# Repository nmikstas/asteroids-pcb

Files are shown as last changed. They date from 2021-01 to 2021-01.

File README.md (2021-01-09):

# asteroids-pcb
PCB source for the original Asteroids arcade game. This is a reproduction of a rev. 2 PCB. There are two sets of gerber files: the main Asteroids PCB and a small adapter board for IC 8C. 8C was a masked ROM that is no longer available. The adapter PCB will allow a 2716 EPROM to be used in it's place. A 28C16A-25 flash ROM will also work.

# NOTE
This project is part of my project portfolio: https://nmikstas.github.io/portfolio/

# Folder Structure
* Asteroids_PCB - The Kicad design files for the Asteroids PCB
* ROM_to_2716 - The Kicad source files for the ROM to EPROM adapter PCB
* Gerbers_Asteroids - The gerber files for the Asteroids PCB
* Gerbers_ROM_to_EPROM - The gerber files for the ROM to EPROM adapter PCB
* BOM - Bill of materials for the Asteroids PCB

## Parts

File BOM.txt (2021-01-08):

COMPONENT ID                              QUANTITY  PART NUMBER                   DESCRIPTION

A_6                                       1         Digikey 450-1650-ND           Push button switch (two pins cut off)
A_7, D_4, R_8                             3         Digikey 296-1668-5-ND         LS74 IC FF D-TYPE DUAL 1BIT 14DIP
A_8                                       1         Digikey 296-1634-5-ND         LS10 IC GATE NAND 3CH 3-INP 14DIP
A_9                                       1         Digikey 296-14711-5-ND        LS109 IC FF JK TYPE DUAL 1BIT 16DIP
A_10, BC_10, C_10, DE_10, E_10, FH_10,    11        Digikey 296-1645-5-ND         LS157 IC QUAD 2-1 DATA SEL/MUX 16-DIP 
F_3, H_3, J_3, K_3, F_6
A_12, C_12                                2         Digikey 296-1781-5-ND         TL082 J-FET Amplifier 2 Circuit 8-PDIP 
BC_12, E_12                               2         Digikey TL081IP-ND            TL081 J-FET Amplifier 1 Circuit 8-PDIP
B_2, C_2                                  2         Digikey 296-1653-5-ND         LS244 8 bits Bus Buffer 3 State out
B_4, D_5                                  2         Digikey 296-1665-5-ND         LS393 IC DUAL 4-BIT BINARY CNTR 14-DIP
B_5, H_10, L_5                            3         Digikey 296-1629-5-ND         LS04 IC INVERTER 6CH 6-INP 14DIP
B_6                                       1         Digikey 296-1643-5-ND         LS14 IC INVERTER SCHMITT 6CH 14DIP
B_7, C_5, C_7, D_7, P_8 C_4               6         Digikey 296-1646-5-ND         LS161 IC 4-BIT SYNC COUNTER 16-DIP
B_8, E_6, K_6, R_7                        4         Digikey 296-1633-5-ND         LS08 IC GATE AND 4CH 2-INP 14DIP
B_9, M_5, N_6                             3         Digikey 296-1658-5-ND         LS32 IC GATE OR 4CH 2-INP 14DIP 
B_10, D_10                                2         Digikey 296-1662-5-ND         LS374 IC FF D-TYPE SNGL 8BIT 20DIP 
B_11, D_11                                2         Found on Ebay or AliExpress   AD561J IC DAC 10BIT MONO VOLT IN 16DIP 
B_12, D_12, M_9, N_10, R_11               5         Digikey 296-9204-5-ND         4016B IC SWITCH QUAD 14DIP    
C_1, DE_1, F_1, NP_3 C_8                  5         Jameco 40002                  M2716 EPROM 2048 X 8 ****C_8 on adapter board****
C_3                                       1         Found on Ebay or AliExpress   R65C02 8-bit microprocessor
C_6, N_5                                  2         Digikey 296-1478-5-ND         LS00 IC GATE NAND 4CH 2-INP 14DIP 
K_5, C_9, D_9, E_9, F_9, H_9, J_9         7         Digikey 296-14886-5-ND        LS191 IC SYNC UP/DOWN COUNTER 16-DIP
D_2, E_2, M_4, N_4, P_4, R_4              6         Jameco 38957                  2114 RAM 1024 X 4 
D_6                                       1         Digikey 296-1627-5-ND         LS02 IC GATE NOR 4CH 2-INP 14DIP
D_8, F_10, N_7, N_11, P_7                 5         Digikey 296-3664-5-ND         LS174 IC FF D-TYPE SNGL 6BIT 16DIP
E_3, R_2                                  2         Digikey 296-1655-5-ND         LS245 Octal BUS Transceivers, 3 State out  
E_4, L_3                                  2         Digikey 296-1640-5-ND         LS139 IC DUAL 2-4 LINE DECODER 16-DIP 
E_5                                       1         Digikey 296-3670-5-ND         LS20 IC GATE NAND 2CH 4-INP 14DIP 
E_7, E_8, L_6                             3         Digikey 296-27985-5-ND        LS42 IC 4-LINE BCD/DEC DECOD 16-DIP
F_4, H_4, J_4                             3         Digikey 296-34025-5-ND        LS670 IC 4X4 REG FILE TRI-ST 16-DIP
F_5, H_5, J_5                             3         Digikey 296-1649-5-ND         LS193 IC 4-BIT UP/DOWN COUNTER 16-DIP
F_7, H_7, J_7, K_7                        4         Digikey 296-1657-5-ND         LS273 IC FF D-TYPE SNGL 8BIT 20DIP
F_8, H_8, J_8, K_8                        4         Jameco 50796                  SN7497 Rate Multiplier
H_6, J_6                                  2         Digikey 296-3701-5-ND         LS367 IC BUF NON-INVERT 5.25V 16DIP
J_10, L_10                                2         Digikey 296-14888-5-ND        LS251 IC 8-IN DATASELCT/MUX 3ST 16DIP 
K_9, P_9, R_9                             3         Digikey 296-1647-5-ND         LS164 IC 8-BIT SHIFT REGISTER 14-DIP
L_8, P_11                                 2         Digikey 296-9542-5-ND         LM324 IC OPAMP GP 1.2MHZ 14DIP 
L_9, M_8, N_8, R_10                       4         Digikey 296-1411-5-ND         555 IC OSC SINGLE TIMER 100KHZ 8-DIP
M_6                                       1         Digikey 296-31579-1-ND        HC283 ****IC 4BIT BINARY FULL ADDER 16SOIC on adapter board****
M_7                                       1         Digikey 296-1648-5-ND         LS175 IC FF D-TYPE SNGL 4BIT 16DIP
M_10                                      1         Digikey 296-14889-5-ND        LS259 IC 8-BIT ADDRESSBLE LATCH 16-DIP
M_12                                      1         Digikey 450-1404-ND           SWITCH ROCKER DIP SPST 60MA 5V  
N_9                                       1         Digikey 296-15069-5-ND        LS06 IC INVERTER OPEN COL 6CH 14DIP
P_5                                       1         Digikey 296-1669-5-ND         LS86 IC GATE XOR 4CH 2-INP 14DIP  
P_6                                       1         Digikey 296-33981-5-ND        LS253 IC 4-1 DATA SELECT/MUX 16-DIP
P_10                                      1         Found on Ebay or AliExpress   NE566 VCO ****WARNING**** There are many Chinese knockoffs floating around that do not work! Avoid LM566!
R_6                                       1         Digikey 450-1417-ND           SWITCH ROCKER DIP SPST 60MA 5V  
U7805                                     1         Digikey 497-1443-5-ND         IC REG LINEAR 5V 1.5A TO220AB 
U7812                                     1         Digikey LM340T-12/NOPB-ND     IC REG LINEAR 12V 1A TO220-3 
U7815                                     1         Digikey 497-8352-5-ND         IC REG LINEAR 15V 1.5A TO220AB 
U7915                                     1         Digikey LM7915CT/NOPB-ND      IC REG LINEAR -15V 1.5A TO220-3 
Y1                                        1         Digikey X429-ND               CRYSTAL 12.0960MHZ SERIES T/H
C1, C2, C3, C4, C5, C6, C7, C8, C9, C10,  78        Digikey 399-4491-1-ND         CAP CER 0.1UF 50V X7R AXIAL  
C11, C12, C13, C14, C15, C16, C17, C18, 
C20, C21, C22, C23, C26, C28, C29, C30, 
C31, C34, C41, C42, C43, C44, C49, C52, 
C53, C57, C60, C61, C65, C66, C71, C72, 
C73, C74, C75, C76, C77, C78, C79, C80, 
C81, C82, C83, C84, C85, C91, C94, C111, 
C112, C37, C51, C54, C63, C95, C96, C99, 
C100, C103, C104, C107, C108, C114, C115, 
C116, C120, C121, C122, C123
C19                                       1         Digikey 1572-1048-ND          100µF 25V Aluminum Electrolytic Capacitors Axial
C24, C35, C47, C50, C62, C113             6         Digikey 399-13735-1-ND        1uf CAP CER 1UF 50V X7R AXIAL
C25, C70, C90, C92, C93                   5         Digikey 1572-1279-ND          CAP ALUM 1UF 20% 50V AXIAL
C27, C32, C36, C40, C55, C58              6         Digikey 399-4453-1-ND         10000pF Unpolarized capacitor
C33                                       1         Digikey 399-14070-1-ND        .22uF Unpolarized capacitor  
C38, C39, C45, C48                        4         Digikey 399-13620-ND          CAP TANT 10UF 20% 20V AXIAL 
C46                                       1         Digikey 399-4512-1-ND         .047uf Unpolarized capacitor  
C56                                       1         Digikey 399-4450-1-ND         1000pf Unpolarized capacitor  
C59                                       1         Digikey 445-173538-1-ND       270pf Unpolarized capacitor  
C64, C67, C68, C69                        4         Digikey 478-3154-1-ND         CAP CER 0.1UF 100V Z5U AXIAL 
C86, C87                                  2         Digikey 1572-1496-ND          CAP ALUM 470UF 20% 35V AXIAL
C88                                       1         Digikey 445-173545-1-ND       390pf Unpolarized capacitor  
C89                                       1         Digikey 399-4447-1-ND         100pf Unpolarized capacitor  
C97, C105                                 2         Digikey CF14JT6K80CT-ND       *****6.8k Resistor***** 
C98, C106, C118, C119                     4         Digikey C410C221J1G5TA7200    220pf Unpolarized capacitor  
C102, C110                                2         Digikey 399-9746-ND           68pf Unpolarized capacitor   
C117                                      1         Digikey 1572-1393-ND          CAP ALUM 22UF 20% 35V AXIAL
CR1, CR2, CR3, CR4, CR6, CR7, CR8, CR15   8         Digikey 1N914FS-ND            1N914 Diode
CR5                                       1         Digikey 732-5015-ND           LED Blue
CR9, CR10, CR11, CR12                     4         Digikey 641-1310-1-ND         1N4001 Diode
CR13, CR14                                2         Digikey 1N756ACSCT-ND         DIODE ZENER 8.2V 500MW DO35
L2, L3, L4, L5, L6, L7, L8, L12           8         Digikey 77F101J-TR-RCCT-ND    FIXED IND 100UH 275MA 2.5 OHM TH
Plastic tabs                              7         Digikey RPC1553-ND            MOUNTING BUTTON 0.330" NYLN NRTL
Q1, Q2, Q3, Q4, Q5, Q7, Q10, Q16, Q17     9         Digikey 2N3906-APCT-ND        Transistor PNP (general) 
Q6, Q8, Q9, Q14, Q15                      5         Digikey 2N3904-APCT-ND        Transistor NPN (general)  
Q11, Q12, Q13                             3         Digikey TIP122GOS-ND          Darlington Transistor NPN (general)
R120, R126                                2         Digikey 3352H-103LF-ND        10k Potentiometer 
R116, R122                                2         Digikey CF14JT3K30CT-ND       3.3k Resistor  
R1, R2, R3, R4, R5, R6, R7, R8, R34,      12        Digikey CF14JT22K0CT-ND       22K Resistor  
R41, R45, R50
R9, R10, R11, R12, R13, R14, R15, R16,    31        Digikey CF14JT10K0CT-ND       10K Resistor
R17, R18, R28, R33, R69, R110, R111,
R130, R131, R38, R54, R58, R59, R60,
R63, R70, R79, R80, R103, R135, R136, 
R138, R139
R19, R20, R21, R22, R23, R24, R25, R26,   22        Digikey CF14JT470RCT-ND       470 Resistor
R32, R87, R88, R89, R90, R91, R92, R93,
R94, R95, R96, R97, R98, R99
R27, R29, R86, R53, R73, R85, R132, R134  8         Digikey CF14JT1K00CT-ND       1K Resistor 
R30, R31                                  2         Digikey CF14JT330RCT-ND       330 Resistor 
R115                                      1         Digikey CF14JT220RCT-ND       220 Resistor
R35, R100                                 2         Digikey CF14JT1K20CT-ND       1.2k Resistor  
R36, R55, R75, R117, R123, R133, R141     7         Digikey CF14JT2K20CT-ND       2.2k Resistor
R37, R137, R140, R144 R82, R102           6         Digikey CF14JT4K70CT-ND       4.7k Resistor 
R39, R64, R106, R107, R108                5         Digikey CF14JT3K90CT-ND       3.9k Resistor
R40, R62, R67                             3         Digikey PPC5.6KW-1CT-ND       5.6k Resistor  
R42, R76, R114, R44, R48, R78, R83        7         Digikey CF14JT47K0CT-ND       47k Resistor
R43                                       1         Digikey CF14JT12K0CT-ND       12k Resistor  
R46, R81, R84, R143                       4         Digikey CF14JT100KCT-ND       100K Resistor  
R47                                       1         Digikey CF14JT220KCT-ND       220K Resistor  
R49 R104, R128, R129                      4         Digikey CF14JT6K80CT-ND       6.8K Resistor
R51, R146                                 2         Digikey CF14JT18K0CT-ND       18K Resistor  
R52                                       1         Digikey CF14JT33K0CT-ND       33k Resistor   
R56, R65, R74, R142                       4         Digikey CF14JT3K30CT-ND       3.3k Resistor
R57, R61                                  2         Digikey CF14JT680RCT-ND       680  Resistor  
R66                                       1         Digikey CF14JT2K70CT-ND       2.7k Resistor  
R68                                       1         Digikey CF14JT15K0CT-ND       15k Resistor  
R71                                       1         Digikey CF14JT68R0CT-ND       68 Resistor  
R72                                       1         Digikey CF14JT68R0CT-ND       27 Resistor    
R77                                       1         Digikey CF14JT39K0CT-ND       39K Resistor  
R101                                      1         Digikey CF14JT270KCT-ND       270k Resistor  
R105, R109                                2         Digikey CF14JT120RCT-ND       120 Resistor  
R112, R113                                2         Digikey CF14JT270RCT-ND       270 Resistor   
R145                                      1         Digikey CF14JT56K0CT-ND       56K Resistor
T1, T2, T3, T4, T5, T6, T7, T8, T9, T10,  17        NONE                          Test point
T11, T12, T13, T14, T15, T16, T17  

****Sockets****
8-pin:                                    9         Jameco 112206                 8-Pin IC Socket Dual Wipe Low Profile 0.30 Inch Wide
14-pin:                                   33        Jameco 112214                 Socket IC 14-Pin Dual Wipe Low Profile 0.3 Inch Wide
16-pin:                                   55        Jameco 112222                 IC Socket 16-Pin Dual Wipe Low Profile 0.3 Inch Wide
18-pin:                                   6         Jameco 112231                 18-Pin 0.3 Inch Wide Low Profile Dual Wipe IC Socket
20-pin:                                   10        Jameco 112248                 20-Pin 0.3 Inch Wide Low Profile Dual Wipe IC Socket
24-pin:                                   4         Jameco 112264                 24-Pin Dual Wipe Low Profile IC Socket 0.6 Inch Wide
40-pin:                                   1         Jameco 112311                 40-Pin Dual Wipe Low Profile IC Socket 0.60 Inch Wide

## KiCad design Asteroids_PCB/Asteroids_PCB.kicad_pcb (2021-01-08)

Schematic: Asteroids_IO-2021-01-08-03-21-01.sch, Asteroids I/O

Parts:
A_12: 082; DIP8
BC_12: 081; DIP8
B_11: AD561J; DIP16
B_11A1: ALT_DAC
B_12: 4016B; DIP14
C24, C35, C47, C50, C62: 1uf; TantC
C27, C32: .01uF; DiskC
C33: .22uF; Mylar_C
C34, C65, C71, C72, C73, C74, C75, C76, C77, C78, C79, C80, C81, C82, C83: .1uF; GenericC
C36, C40, C55, C58: .01uf; DiskC
C37, C51, C54, C63, C95, C96, C99, C100, C103, C104, C107, C108, C114, C115, C116, C120, C121, C122, C123: .1uf; GenericC
C38, C39, C45, C48: 10uf; TantC2
C46: .047uf; Mylar_C
C56: .001uf; DiskC
C59: 270pf; Mylar_C
C64: .1uF; Mylar_C
C67, C68, C69: .1uf; Mylar_C
C88: 390pf; SmallC
C89: 100pf; SmallC
C97, C105: 10pf; SmallC
C98, C106, C118, C119: 220pf; SmallC
C102, C110: 68pf; SmallC
C113: 1uF; TantC
CR2, CR3, CR4, CR6, CR7, CR8: 1N914; Diode1
CR15: 1N914; GenericR
C_6: LS00; DIP14
C_12: 082; DIP8
D_6: LS02; DIP14
D_11: AD561J; DIP16
D_11A1: ALT_DAC
D_12: 4016B; DIP14
E_12: 081; DIP8
H_10: LS04; DIP14
J20: J20
J21: J21
J_10: LS251; DIP16
K_9: LS164; DIP14
L2, L3, L4, L5, L6, L7, L8, L12: 100uH; GenericL
L_5: LS04; DIP14
L_8: 324; DIP14
L_9: 555; DIP8
L_10: LS251; DIP16
M_8: 555; DIP8
M_9: 4016B; DIP14
M_10: LS259; DIP16
M_12: SW_DIP_x04; DIP8
N_5: LS00; DIP14
N_6: LS32; DIP14
N_7, N_11: LS174_; DIP16
N_8: 555; DIP8
N_9: LS06; DIP14
N_10: 4016B; DIP14
P_2: DIP20_DUMMY; DIP20
P_5: LS86; DIP14
P_6: LS253; DIP16
P_7: LS174_; DIP16
P_8: LS161; DIP16
P_9: LS164; DIP14
P_10: 566; DIP8
P_11: 324; DIP14
Q1, Q2, Q3, Q4, Q5, Q7, Q10, Q16, Q17: 2N3906; GenericQ
Q6: 2N3643; GenericQ
Q8, Q9: 2N3904; GenericQ
Q11, Q12, Q13: 2N6044
Q14, Q15: MPSA06S; GenericQ
R19, R20, R21, R22, R23, R24, R25, R26, R87, R88, R89, R90, R91, R92, R93, R94, R95, R96, R97, R98, R99: 470; GenericR
R34, R41: 22k; GenericR
R35, R100: 1.2k; GenericR
R36, R75, R117, R123, R133: 2.2k; GenericR
R37, R137, R140, R144: 4.7k; GenericR
R38, R54, R58, R59, R60, R63, R70, R79, R80, R103, R116, R122, R135, R136, R138, R139: 10k; GenericR
R39, R64, R106, R107, R108: 3.9k; GenericR
R40, R62, R67: 5.6k; GenericR
R42, R76, R114: 47k; GenericR
R43: 12k; GenericR
R44, R48, R78, R83: 47K; GenericR
R45, R50: 22K; GenericR
R46, R81, R84, R143: 100K; GenericR
R47: 220K; GenericR
R49: 6.8K; GenericR
R51, R146: 18K; GenericR
R52: 33k; GenericR
R53, R73, R85, R132, R134: 1k; GenericR
R56, R65: 3.3k; GenericR
R57, R61: 680; GenericR
R66: 2.7k; GenericC
R68: 15k; GenericR
R69, R110, R111: 10K; GenericR
R71: 68; GenericR
R72: 27; GenericR
R74, R142: 3.3K; GenericR
R77: 39K; GenericR
R82, R102: 4.7K; GenericR
R86: 1K; GenericR
R101: 270k; GenericR
R104, R128, R129: 6.8k; GenericR
R105, R109: 120; GenericR
R115: 330; GenericR
R120, R126: 10k; Pot
R141: 2.2K; GenericR
R145: 56K; GenericR
R_3: 8316E; DDIP24
R_6: SW_x08; DIP16
R_7: LS08; DIP14
R_8: LS74; DIP14
R_9: LS164; DIP14
R_10: 555; DIP8
R_11: 4016B; DIP14
T1: TPAD1; TPAD
T2: TPAD2; TPAD
T3: TPAD3; TPAD
T4: TPAD4; TPAD
T5: TPAD5; TPAD
T6: TPAD6; TPAD
T7: TPAD7; TPAD
T10, T11, T12, T13, T14, T15, T16, T17: TPAD
TP10: START 2; TEST_POINT
TP11: START 1; TEST_POINT
TP12: COIN R; TEST_POINT
TP13: COIN C; TEST_POINT
TP14: COIN L; TEST_POINT
TP20: AUD 1; TEST_POINT
TP50: X_OUT; TEST_POINT
TP60: Y_OUT; TEST_POINT
TP70: Z_OUT; TEST_POINT

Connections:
3KHz: L_10.3, R_11.11; also elsewhere on the board
3MHz: C_6.2, C_6.13, K_9.8; also elsewhere on the board
12KHz: D_6.2, P_8.2, P_9.8, R_9.8; also elsewhere on the board
22V0: C37.1, C65.2, L_8.4, P_11.4; also elsewhere on the board
36VAC1_: J20.X; also elsewhere on the board
36_VAC2_: J20.20; also elsewhere on the board
+5DAC: B_11.14, B_11A1.20, C96.2, C104.2, D_11.14, D_11A1.20; also elsewhere on the board
+5V: C34.1, C51.1, C54.1, C62.1, C63.2, C_6.14, D_6.14, H_10.14, J20.2, J20.21, J20.B, J20.Y, J21.45, J21.46, J21.47, J21.48, J21.49, J21.50, J_10.16, K_9.14, L_5.14, L_9.8, L_10.16, M_8.8, M_9.1, M_9.3, M_9.9, M_9.10, M_10.16, N_5.14, N_6.14, N_7.16, N_8.8, N_9.14, N_11.16, P_2.20, P_5.14, P_6.16, P_7.16, P_8.16, P_9.14, P_11.3, P_11.5, P_11.10, P_11.12, Q9.3, R19.1, R20.1, R21.1, R22.1, R23.1, R24.1, R25.1, R26.1, R39.1, R49.1, R50.1, R67.1, R71.1, R79.1, R80.1, R87.2, R88.2, R89.2, R90.2, R91.2, R92.2, R93.2, R94.2, R95.2, R96.2, R97.2, R98.2, R99.2, R100.1, R132.2, R134.1, R_3.21, R_3.24, R_7.14, R_8.14, R_9.14, R_10.4, R_10.8, R_11.14; also elsewhere on the board
+8.2V: B_12.14, CR15.1, D_12.14, Q10.1, Q16.1, Q17.1, R141.1, R144.1; also elsewhere on the board
+12V: CR3.2, M_9.14, N_10.14, P_10.8, R52.1, R54.1, R56.1, R59.1, R60.1, R62.1, R63.1, R65.1, R70.1, R85.1; also elsewhere on the board
+15V: A_12.8, BC_12.7, C100.2, C108.2, C121.2, C123.2, C_12.8, E_12.7; also elsewhere on the board
-8.2V: B_12.7, D_12.7, R115.2, R142.2, R145.2; also elsewhere on the board
-15V: A_12.4, BC_12.4, B_11.3, B_11A1.17, C95.1, C99.2, C103.1, C107.2, C120.2, C122.2, C_12.4, D_11.3, D_11A1.17, E_12.4; also elsewhere on the board
A0: J21.17; also elsewhere on the board
A1: J21.18; also elsewhere on the board
A2: J21.15; also elsewhere on the board
A3: J21.16; also elsewhere on the board
A4: J21.13; also elsewhere on the board
A5: J21.14; also elsewhere on the board
A6: J21.11; also elsewhere on the board
A7: J21.12; also elsewhere on the board
A8: J21.9; also elsewhere on the board
A9: J21.10; also elsewhere on the board
A10: J21.7; also elsewhere on the board
A11: J21.8; also elsewhere on the board
A12: J21.21; also elsewhere on the board
A13: J21.22; also elsewhere on the board
A14: J21.19; also elsewhere on the board
A15: J21.20; also elsewhere on the board
AB0: J_10.11, L_10.11, M_10.1, P_6.14; also elsewhere on the board
AB1: J_10.10, L_10.10, M_10.2, P_6.2; also elsewhere on the board
AB2: J_10.9, L_10.9, M_10.3; also elsewhere on the board
AB8: P_5.4; also elsewhere on the board
AB9: N_5.5; also elsewhere on the board
AB10: L_5.5; also elsewhere on the board
AB12: D_6.8; also elsewhere on the board
AM0: R_3.8; also elsewhere on the board
AM1: R_3.7; also elsewhere on the board
AM2: R_3.6; also elsewhere on the board
AM3: R_3.5; also elsewhere on the board
AM4: R_3.4; also elsewhere on the board
AM5: R_3.3; also elsewhere on the board
AM6: R_3.2; also elsewhere on the board
AM7: R_3.1; also elsewhere on the board
AM8: R_3.23; also elsewhere on the board
AM9: R_3.22; also elsewhere on the board
AM10: L_5.3, R_3.19; also elsewhere on the board
AUDIO_1_: C113.2, J20.5, P_11.8, R86.1, TP20.1, TP20.2
AUDIO_2_: J20.E, P_11.14, R110.1
BVLD: K_9.2; also elsewhere on the board
C1: C115.1, J20.4, M_12.7, M_12.8, Q11.2
C_CN_SW_: C81.2, J20.12, L7.1
D0: J21.29; also elsewhere on the board
D1: J21.30; also elsewhere on the board
D2: J21.27; also elsewhere on the board
D3: J21.28; also elsewhere on the board
D4: J21.25; also elsewhere on the board
D5: J21.26; also elsewhere on the board
D6: J21.23; also elsewhere on the board
D7: J21.24; also elsewhere on the board
DACX1*: D_11.4, D_11A1.12; also elsewhere on the board
DACX2*: D_11.5, D_11A1.11; also elsewhere on the board
DACX3*: D_11.6, D_11A1.10; also elsewhere on the board
DACX4*: D_11.7, D_11A1.9; also elsewhere on the board
DACX5*: D_11.8, D_11A1.8; also elsewhere on the board
DACX6*: D_11.9, D_11A1.7; also elsewhere on the board
DACX7*: D_11.10, D_11A1.6; also elsewhere on the board
DACX8*: D_11.11, D_11A1.5; also elsewhere on the board
DACX9*: D_11.12, D_11A1.4; also elsewhere on the board
DACX10*: D_11.13, D_11A1.3; also elsewhere on the board
DACY1*: B_11.4, B_11A1.12; also elsewhere on the board
DACY2*: B_11.5, B_11A1.11; also elsewhere on the board
DACY3*: B_11.6, B_11A1.10; also elsewhere on the board
DACY4*: B_11.7, B_11A1.9; also elsewhere on the board
DACY5*: B_11.8, B_11A1.8; also elsewhere on the board
DACY6*: B_11.9, B_11A1.7; also elsewhere on the board
DACY7*: B_11.10, B_11A1.6; also elsewhere on the board
DACY8*: B_11.11, B_11A1.5; also elsewhere on the board
DACY9*: B_11.12, B_11A1.4; also elsewhere on the board
DACY10*: B_11.13, B_11A1.3; also elsewhere on the board
DB0: N_7.6, N_11.14, P_2.17, P_6.7; also elsewhere on the board
DB1: N_7.11, N_11.3, P_2.18, P_6.9; also elsewhere on the board
DB2: N_7.4, N_11.13, P_2.19, P_7.6; also elsewhere on the board
DB3: N_7.13, N_11.4, P_2.16, P_7.11; also elsewhere on the board
DB4: N_7.3, N_11.11, P_2.15, P_7.4; also elsewhere on the board
DB5: N_11.6, P_2.14, P_7.13; also elsewhere on the board
DB6: P_2.13, P_7.3; also elsewhere on the board
DB7: J_10.6, L_10.6, M_10.13, P_2.12, P_7.14; also elsewhere on the board
DDMA0: P_2.3, R_3.9; also elsewhere on the board
DDMA1: P_2.2, R_3.10; also elsewhere on the board
DDMA2: P_2.1, R_3.11; also elsewhere on the board
DDMA3: P_2.4, R_3.13; also elsewhere on the board
DDMA4: P_2.5, R_3.14; also elsewhere on the board
DDMA5: P_2.6, R_3.15; also elsewhere on the board
DDMA6: P_2.7, R_3.16; also elsewhere on the board
DDMA7: P_2.8, R_3.17; also elsewhere on the board
DIAG_STEP_: C71.2, J20.K, L4.1
EXPAUD0: P_7.12, R_7.1
EXPAUD1: P_7.5, R_7.12
EXPAUD2: P_7.10, R_7.4
EXPAUD3: P_7.7, R_7.9
EXPITCH0: L_5.11, N_6.12, P_7.2, P_8.4
EXPITCH1: N_6.13, P_7.15, P_8.3
EXPLOSND: C24.2, R40.1, R41.1, R42.1, R43.1, R82.2
FIRE_: C72.2, J20.T, L_10.15, R89.1
GND: B_11.1, B_11A1.1, B_11A1.2, B_11A1.13, B_11A1.19, C24.1, C27.2, C32.2, C33.2, C34.2, C35.2, C36.2, C37.2, C38.2, C39.1, C40.2, C45.2, C46.2, C47.2, C48.1, C50.2, C51.2, C54.2, C55.2, C58.2, C63.1, C64.2, C65.1, C71.1, C72.1, C73.1, C74.1, C75.1, C76.1, C77.1, C78.1, C79.1, C80.1, C81.1, C82.1, C83.1, C95.2, C96.1, C98.2, C99.1, C100.1, C103.2, C104.1, C106.2, C107.1, C108.1, C114.2, C115.2, C116.2, C118.2, C119.2, C120.1, C121.1, C122.1, C123.1, CR7.1, C_6.7, D_6.7, D_11.1, D_11A1.1, D_11A1.2, D_11A1.13, D_11A1.19, H_10.7, J20.1, J20.11, J20.22, J20.A, J20.U, J20.V, J20.Z, J21.1, J21.2, J21.3, J21.4, J21.5, J21.6, J_10.8, K_9.7, L_5.7, L_8.5, L_8.10, L_8.11, L_9.1, L_10.8, M_8.1, M_9.7, M_10.8, N_5.7, N_6.7, N_7.8, N_8.1, N_9.7, N_10.1, N_10.3, N_10.7, N_11.8, P_2.10, P_5.7, P_6.8, P_7.8, P_8.8, P_9.7, P_10.1, P_11.11, Q7.3, Q8.1, Q11.3, Q12.3, Q13.3, Q14.1, Q15.1, R34.2, R44.2, R53.2, R72.2, R116.2, R122.2, R128.2, R129.2, R137.2, R140.2, R_3.12, R_3.18, R_6.1, R_6.2, R_6.3, R_6.4, R_6.5, R_6.6, R_6.7, R_6.8, R_7.7, R_8.7, R_9.7, R_10.1, R_11.7; also elsewhere on the board
GO: H_10.1; also elsewhere on the board
GW: C_6.3; also elsewhere on the board
HALT: L_10.2; also elsewhere on the board
HYPRSPC_: C73.2, J20.10, L_10.1, R88.1
INV: B_12.13, D_12.13, Q16.3, R142.1, R143.2
L1: C114.1, J20.D, M_12.1, Q12.2
LIFEEN: M_10.10, R79.2, R_11.12
LIFESND: R78.2, R_11.10
L_CN_SW_: C82.2, J20.13, L5.1
NINV: B_12.12, D_12.12, Q17.3, R145.1
NOISE: N_5.3, R_8.12, R_9.1, R_9.2, R_11.9
NO_CON: J20.19, R146.2
unnamed 204: D_6.12; also elsewhere on the board
unnamed 206: L_5.12; also elsewhere on the board
unnamed: A_12.2, C110.1, R122.1, R126.3
unnamed: A_12.3, B_12.2, B_12.10
unnamed: A_12.5, R129.1
unnamed: A_12.7, B_12.8, C105.1, R123.1, R135.2
unnamed: BC_12.2, R135.1, R136.2
unnamed: BC_12.3, R137.1
unnamed: BC_12.6, B_12.4, R136.1
unnamed 223: C_6.1; also elsewhere on the board
unnamed 232: C_6.5; also elsewhere on the board
unnamed: B_11.16, R123.2
unnamed: B_11A1.14, T7.1
unnamed: B_11A1.15, T6.1
unnamed: B_11A1.16, T5.1
unnamed: B_12.1, B_12.3, C118.1
unnamed: B_12.9, B_12.11, C106.1
unnamed: C27.1, CR2.1, Q2.2, R44.1, R45.1, R46.1, R47.1, R48.1
unnamed: C32.1, N_8.5
unnamed: C33.1, N_8.2, N_8.6, Q2.3, R51.2
unnamed: C35.1, M_8.2, M_8.6, R57.2
unnamed: C36.1, M_8.5
unnamed: C38.1, L_8.3, M_9.4, Q3.3
unnamed: C39.2, M_9.8, R58.1
unnamed: C40.1, L_9.5
unnamed: C45.1, N_10.2, N_10.9, Q6.2, R69.2, R_10.2, R_10.6
unnamed: C46.1, P_10.7
unnamed: C47.1, L_8.12, M_9.11, Q1.3
unnamed: C48.2, M_9.2, R66.1
unnamed: C50.1, L_9.2, L_9.6, R61.2
unnamed: C55.1, R_10.5
unnamed: C56.1, P_10.6, R70.2
unnamed: C56.2, P_10.5, Q6.3, R62.2
unnamed: C58.1, Q7.1, Q8.3, Q9.2, R71.2
unnamed: C59.1, Q8.2, R73.1
unnamed: C59.2, H_10.4, R73.2
unnamed: C62.2, R75.1, R76.2
unnamed: C64.1, N_8.3, R74.1
unnamed: C67.1, P_11.7, R101.1, R104.2
unnamed: C67.2, C68.1, R76.1, R100.2
unnamed: C68.2, P_11.6, R101.2
unnamed: C69.2, P_11.2, R103.2, R104.1
unnamed: C88.1, C89.1, CR15.2, Q10.2, R114.1
unnamed: C88.2, C_6.11, R114.2
unnamed: C97.1, C_12.7, D_12.8, R117.1, R138.2
unnamed: C97.2, C_12.6, D_11.2, D_11.15
unnamed: C98.1, D_12.9, D_12.11
unnamed: C102.1, C_12.2, R116.1, R120.3
unnamed: C113.1, R111.2
unnamed: C119.1, D_12.1, D_12.3
unnamed: CR2.2, R49.2
unnamed: CR3.1, CR4.2
unnamed: CR4.1, Q1.2, Q3.2, R53.1
unnamed: CR6.1, M_8.3
unnamed: CR7.2, N_10.4, R64.1
unnamed: CR8.1, L_9.3
unnamed 305: C_6.6; also elsewhere on the board
unnamed 306: C_6.8; also elsewhere on the board
unnamed: C_6.10, D_6.10
unnamed 321: L_5.13; also elsewhere on the board
unnamed 327: H_10.13; also elsewhere on the board
unnamed 330: H_10.6; also elsewhere on the board
unnamed: C_12.3, D_12.2, D_12.10
unnamed: C_12.5, R128.1
unnamed 334: P_5.6; also elsewhere on the board
unnamed: D_6.1, R_8.11
unnamed: D_6.3, L_5.2, P_8.9
unnamed 348: D_6.4; also elsewhere on the board
unnamed 349: D_6.5, D_6.9; also elsewhere on the board
unnamed 350: D_6.11; also elsewhere on the board
unnamed: D_11.16, R117.2
unnamed: D_11A1.14, T4.1
unnamed: D_11A1.15, T3.1
unnamed: D_11A1.16, T2.1
unnamed: D_11A1.18, T1.1
unnamed: D_12.4, E_12.6, R139.1
unnamed: E_12.2, R138.1, R139.2
unnamed: E_12.3, R140.1
unnamed 397: H_10.11; also elsewhere on the board
unnamed 400: H_10.8; also elsewhere on the board
unnamed: H_10.3, K_9.3
unnamed 409: H_10.5; also elsewhere on the board
unnamed 410: H_10.9; also elsewhere on the board
unnamed: J_10.1, L8.2, R93.1, TP11.1, TP11.2
unnamed: J_10.2, L12.2, R98.1, TP12.1, TP12.2
unnamed: J_10.3, L7.2, R97.1, TP13.1, TP13.2
unnamed: J_10.4, L5.2, R96.1, TP14.1, TP14.2
unnamed: J_10.15, L6.2, R95.1, TP10.1, TP10.2
unnamed: L3.2, L_10.13, R91.1
unnamed: L4.2, L_10.14, R90.1
unnamed 460: L_5.6; also elsewhere on the board
unnamed: L_5.1, P_8.15
unnamed 464: L_5.4; also elsewhere on the board
unnamed: L_5.10, P_8.5
unnamed: L_8.1, Q4.2
unnamed: L_8.2, Q4.1, R56.2
unnamed: L_8.6, L_8.7
unnamed: L_8.8, L_8.9
unnamed: L_8.13, Q5.1, R65.2
unnamed: L_8.14, Q5.2
unnamed: L_9.7, Q5.3, R61.1
unnamed 486: N_6.8; also elsewhere on the board
unnamed: M_8.7, Q4.3, R57.1
unnamed: M_9.5, M_9.6, N_9.10, R60.2
unnamed: M_9.12, M_9.13, N_9.4, R59.2
unnamed: M_10.6, N_9.1
unnamed: N_5.1, N_5.2, P_5.3
unnamed: N_5.6, P_5.5
unnamed: N_5.8, N_6.9
unnamed: N_6.11, P_8.6
unnamed: N_7.2, N_8.4
unnamed: N_7.5, R48.2
unnamed: N_7.7, R47.2
unnamed: N_7.10, R46.2
unnamed: N_7.12, R45.2
unnamed: N_7.14, N_7.15
unnamed: N_8.7, R51.1
unnamed: N_9.6, N_9.9, R132.1, R133.2
unnamed: N_9.8, Q15.2, R134.2
unnamed: N_10.8, R68.2
unnamed: N_9.12, N_10.13, R85.2
unnamed: N_11.2, R105.1
unnamed: N_11.5, R106.2
unnamed: N_11.7, R107.2
unnamed: N_11.10, R108.2
unnamed: N_11.15, R109.1
unnamed: P_5.1, P_9.12
unnamed: P_5.2, R_9.12
unnamed: P_6.3, R19.2, R_6.16
unnamed: P_6.4, R21.2, R_6.14
unnamed: P_6.5, R23.2, R_6.12
unnamed: P_6.6, R26.2, R_6.10
unnamed: P_6.10, R25.2, R_6.9
unnamed: P_6.11, R24.2, R_6.11
unnamed: P_6.12, R22.2, R_6.13
unnamed: P_6.13, R20.2, R_6.15
unnamed: P_9.1, P_9.2, R_9.13
unnamed: P_11.9, R77.1, R78.1, R81.1, R82.1, R83.1, R84.1, R86.2, R102.1
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

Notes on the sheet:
PLAYER INPUT CIRCUITRY
OPTIONS INPUT CIRCUITRY
VIDEO INVERTER
AUDIO OUTPUT
VIDEO OUTPUTS
LAMP, LED AND COIN COUNTER OUTPUT
MISCELLANEOUS

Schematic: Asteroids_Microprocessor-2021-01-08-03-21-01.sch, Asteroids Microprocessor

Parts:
A_6: RESET; RST
B_2: LS244; DIP20
B_4: LS393; DIP14
B_5: LS04; DIP14
B_6: LS14; DIP14
C1, C2, C3, C4, C5, C6, C7, C8, C9, C10, C11, C12, C13, C14, C15, C16, C17, C18, C20, C21, C22, C23, C26, C28, C29, C30, C31, C41, C42, C43, C44, C49, C52, C53, C57, C60, C61, C66, C84, C85, C91, C94, C111, C112: .1uF; GenericC
C19: 100uF; Electrolytic1
C25, C70, C90, C92, C93: 1uF; Electrolytic2C
C86, C87: 470uF; Electrolytic3
C117: 22uF; Electrolytic4
CR1: 1N914; Diode1
CR5: LED
CR9, CR10, CR11, CR12: 1N4001; GenericD
CR13, CR14: 1N756A; GenericR
C_1: 8316E; DDIP24
C_2: LS244; DIP20
C_3: 6502A
C_4: 9316; DIP16
C_5: LS161; DIP16
C_6: LS00; DIP14
DE_1: 8316E; DDIP24
D_2: 2114; DIP18
D_4: LS74; DIP14
D_5: LS393; DIP14
D_6: LS02; DIP14
E_2: 2114; DIP18
E_3: LS245; DIP20
E_4: LS139; DIP16
E_5: LS20; DIP14
E_6: LS08; DIP14
F_1: 8316E; DDIP24
F_2: 82S137
H_1, H_2: 82S137
J_1, J_2: 82S137
K_1: 82S137
L_1, L_2: 82S137
L_3: LS139; DIP16
L_5: LS04; DIP14
L_6: LS42; DIP16
M_1, M_2: 82S137
M_5: LS32; DIP14
N_1, N_2: 82S137
N_5: LS00; DIP14
PD1, PD2, PD3, PD4: Split_Pad; SP
P_5: LS86; DIP14
R9, R10, R11, R12, R13, R14, R15, R16, R17, R18, R28, R33: 10K; GenericR
R27, R29: 1K; GenericR
R30, R31: 330; GenericR
R32: 470; GenericR
R55: 150; GenericR
R112, R113: 270; GenericR
TP1: WDOG_DISABLE; TEST_POINT
TP2: O2; TEST_POINT
TP3: R/W; TEST_POINT
TP4: 6MHz; TEST_POINT
TP5: +5V; TEST_POINT
TP6, TP7: GND; TEST_POINT
U7805: L7805; Volt_Reg
U7812: L7812; 2N6044
U7815: L7815; Volt_Reg
U7915: L7915; Volt_Reg
Y1: 12.096MHz; RST

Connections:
1.5MHz: B_2.15, C_3.37, C_4.12
3KHz: B_4.8, C_5.2, D_5.1; also elsewhere on the board
3MHz: C_4.13, C_6.2, C_6.13, D_4.3, E_5.12; also elsewhere on the board
6MHz: C_4.14, TP4.1, TP4.2; also elsewhere on the board
12KHz: B_4.10, D_6.2; also elsewhere on the board
22V0: C87.1, CR11.1, CR12.1, U7805.1 (IN), U7812.1 (IN), U7815.1 (IN); also elsewhere on the board
36VAC1_: C84.1, CR10.1, CR11.2; also elsewhere on the board
36_VAC2_: C85.1, CR9.1, CR12.2; also elsewhere on the board
+5DAC: C92.1, U7805.3 (OUT); also elsewhere on the board
+5V: B_2.20, B_4.14, B_5.14, B_6.14, C1.1, C2.1, C3.1, C4.1, C5.1, C6.1, C7.1, C8.1, C9.1, C10.1, C11.1, C12.1, C13.1, C14.1, C15.1, C16.1, C17.1, C19.1, C20.1, C21.1, C22.1, C23.1, C26.1, C28.1, C29.1, C30.1, C31.1, C41.1, C42.1, C43.1, C44.1, C49.1, C52.1, C53.1, C57.1, C60.1, C61.1, C66.1, C111.1, C112.1, CR1.1, C_1.21, C_1.24, C_2.20, C_3.8, C_4.16, C_5.16, C_6.14, DE_1.21, DE_1.24, D_2.18, D_4.14, D_5.14, D_6.14, E_2.18, E_3.20, E_4.16, E_5.14, E_6.14, F_1.21, F_1.24, F_2.18, H_1.18, H_2.18, J_1.18, J_2.18, K_1.18, L_1.18, L_2.18, L_3.16, L_5.14, L_6.16, M_1.18, M_2.18, M_5.14, N_1.18, N_2.18, N_5.14, P_5.14, R9.2, R10.2, R11.1, R12.2, R13.1, R14.2, R15.1, R16.1, R17.1, R18.1, R27.2, R28.1, R29.2, R33.1, R55.1, TP5.1, TP5.2; also elsewhere on the board
+8.2V: C94.1, C117.1, CR14.1, R113.1; also elsewhere on the board
+12V: C70.1, U7812.3 (OUT); also elsewhere on the board
+15V: C93.1, R113.2, U7815.3 (OUT); also elsewhere on the board
-8.2V: C91.1, CR13.2, R112.1; also elsewhere on the board
-15V: C90.1, R112.2, U7915.3 (VO); also elsewhere on the board
A0: C_2.13, C_3.9; also elsewhere on the board
A1: C_2.8, C_3.10; also elsewhere on the board
A2: C_2.11, C_3.11; also elsewhere on the board
A3: C_2.6, C_3.12; also elsewhere on the board
A4: C_2.15, C_3.13; also elsewhere on the board
A5: C_2.4, C_3.14; also elsewhere on the board
A6: C_2.2, C_3.15; also elsewhere on the board
A7: C_2.17, C_3.16; also elsewhere on the board
A8: B_2.6, C_3.17; also elsewhere on the board
A9: B_2.4, C_3.18; also elsewhere on the board
A10: B_2.8, C_3.19; also elsewhere on the board
A11: B_2.13, C_3.20; also elsewhere on the board
A12: B_2.11, C_3.22; also elsewhere on the board
A13: C_3.23, E_4.14; also elsewhere on the board
A14: C_3.24, E_4.13; also elsewhere on the board
A15: C_3.25, PD1.1; also elsewhere on the board
AB0: C_1.8, C_2.7, DE_1.8, D_2.5, E_2.5, F_1.8, F_2.5, H_1.5, H_2.5, J_1.5, J_2.5, K_1.5, L_1.5, L_2.5, M_1.5, M_2.5, N_1.5, N_2.5; also elsewhere on the board
AB1: C_1.7, C_2.12, DE_1.7, D_2.6, E_2.6, F_1.7, F_2.6, H_1.6, H_2.6, J_1.6, J_2.6, K_1.6, L_1.6, L_2.6, M_1.6, M_2.6, N_1.6, N_2.6; also elsewhere on the board
AB2: C_1.6, C_2.9, DE_1.6, D_2.7, E_2.7, F_1.6, F_2.7, H_1.7, H_2.7, J_1.7, J_2.7, K_1.7, L_1.7, L_2.7, M_1.7, M_2.7, N_1.7, N_2.7; also elsewhere on the board
AB3: C_1.5, C_2.14, DE_1.5, D_2.4, E_2.4, F_1.5, F_2.4, H_1.4, H_2.4, J_1.4, J_2.4, K_1.4, L_1.4, L_2.4, M_1.4, M_2.4, N_1.4, N_2.4; also elsewhere on the board
AB4: C_1.4, C_2.5, DE_1.4, D_2.3, E_2.3, F_1.4, F_2.3, H_1.3, H_2.3, J_1.3, J_2.3, K_1.3, L_1.3, L_2.3, M_1.3, M_2.3, N_1.3, N_2.3; also elsewhere on the board
AB5: C_1.3, C_2.16, DE_1.3, D_2.2, E_2.2, F_1.3, F_2.2, H_1.2, H_2.2, J_1.2, J_2.2, K_1.2, L_1.2, L_2.2, M_1.2, M_2.2, N_1.2, N_2.2; also elsewhere on the board
AB6: C_1.2, C_2.18, DE_1.2, D_2.1, E_2.1, F_1.2, F_2.1, H_1.1, H_2.1, J_1.1, J_2.1, K_1.1, L_1.1, L_2.1, M_1.1, M_2.1, N_1.1, N_2.1; also elsewhere on the board
AB7: C_1.1, C_2.3, DE_1.1, D_2.17, E_2.17, F_1.1, F_2.17, H_1.17, H_2.17, J_1.17, J_2.17, K_1.17, L_1.17, L_2.17, M_1.17, M_2.17, N_1.17, N_2.17; also elsewhere on the board
AB8: B_2.14, C_1.23, DE_1.23, F_1.23, F_2.16, H_1.16, H_2.16, J_1.16, J_2.16, K_1.16, L_1.16, L_2.16, M_1.16, M_2.16, N_1.16, N_2.16, P_5.4; also elsewhere on the board
AB9: B_2.16, C_1.22, DE_1.22, D_2.15, E_2.15, F_1.22, F_2.15, H_1.15, H_2.15, J_1.15, J_2.15, K_1.15, L_1.15, L_2.15, L_6.15, M_1.15, M_2.15, N_1.15, N_2.15, N_5.5; also elsewhere on the board
AB10: B_2.12, C_1.19, DE_1.19, E_4.2, F_1.19, F_2.8, H_1.8, H_2.8, J_1.8, J_2.8, K_1.8, L_5.5, L_6.14; also elsewhere on the board
AB11: B_2.7, E_4.3, L_3.2, L_6.13; also elsewhere on the board
AB12: B_2.9, D_6.8, E_5.9, L_3.3; also elsewhere on the board
AM10: L_5.3, M_5.5; also elsewhere on the board
AM11: L_3.14; also elsewhere on the board
AM12: L_3.13; also elsewhere on the board
D0: C_3.33, E_3.18; also elsewhere on the board
D1: C_3.32, E_3.17; also elsewhere on the board
D2: C_3.31, E_3.16; also elsewhere on the board
D3: C_3.30, E_3.15; also elsewhere on the board
D4: C_3.29, E_3.14; also elsewhere on the board
D5: C_3.28, E_3.13; also elsewhere on the board
D6: C_3.27, E_3.12; also elsewhere on the board
D7: C_3.26, E_3.11; also elsewhere on the board
DB0: C_1.9, DE_1.9, D_2.14, E_3.2, F_1.9, H_1.14, J_1.14, K_1.14, L_1.14, M_1.14, N_1.14, R14.1; also elsewhere on the board
DB1: C_1.10, DE_1.10, D_2.13, E_3.3, F_1.10, H_1.13, J_1.13, K_1.13, L_1.13, M_1.13, N_1.13, R12.1; also elsewhere on the board
DB2: C_1.11, DE_1.11, D_2.12, E_3.4, F_1.11, H_1.12, J_1.12, K_1.12, L_1.12, M_1.12, N_1.12, R10.1; also elsewhere on the board
DB3: C_1.13, DE_1.13, D_2.11, E_3.5, F_1.13, H_1.11, J_1.11, K_1.11, L_1.11, M_1.11, N_1.11, R9.1; also elsewhere on the board
DB4: C_1.14, DE_1.14, E_2.14, E_3.6, F_1.14, F_2.14, H_2.14, J_2.14, L_2.14, M_2.14, N_2.14, R11.2; also elsewhere on the board
DB5: C_1.15, DE_1.15, E_2.13, E_3.7, F_1.15, F_2.13, H_2.13, J_2.13, L_2.13, M_2.13, N_2.13, R13.2; also elsewhere on the board
DB6: C_1.16, DE_1.16, E_2.12, E_3.8, F_1.16, F_2.12, H_2.12, J_2.12, L_2.12, M_2.12, N_2.12, R15.2; also elsewhere on the board
DB7: C_1.17, DE_1.17, E_2.11, E_3.9, F_1.17, F_2.11, H_2.11, J_2.11, L_2.11, M_2.11, N_2.11, R16.2; also elsewhere on the board
DVX11: B_6.3; also elsewhere on the board
EXPITCH0: L_5.11; also elsewhere on the board
GND: A_6.1, B_2.1, B_2.10, B_2.19, B_4.2, B_4.7, B_4.12, B_5.7, B_6.7, C1.2, C2.2, C3.2, C4.2, C5.2, C6.2, C7.2, C8.2, C9.2, C10.2, C11.2, C12.2, C13.2, C14.2, C15.2, C16.2, C17.2, C19.2, C20.2, C21.2, C22.2, C23.2, C25.2, C26.2, C28.2, C29.2, C30.2, C31.2, C41.2, C42.2, C43.2, C44.2, C49.2, C52.2, C53.2, C57.2, C60.2, C61.2, C66.2, C70.2, C84.2, C85.2, C86.2, C87.2, C90.2, C91.2, C92.2, C93.2, C94.2, C111.2, C112.2, C117.2, CR5.1, CR13.1, CR14.2, C_1.12, C_1.18, C_2.1, C_2.10, C_2.19, C_3.1, C_3.21, C_4.8, C_5.3, C_5.4, C_5.6, C_5.8, C_6.7, DE_1.12, DE_1.18, D_2.9, D_4.7, D_5.7, D_6.7, E_2.9, E_3.10, E_3.19, E_4.8, E_4.15, E_5.7, E_6.7, F_1.12, F_1.18, F_2.9, H_1.9, H_2.9, J_1.9, J_2.9, K_1.9, L_1.9, L_2.9, L_3.8, L_3.15, L_5.7, L_6.8, M_1.9, M_2.9, M_5.7, N_1.9, N_2.9, N_5.7, PD1.2, PD2.1, PD2.2, PD3.1, PD3.2, PD4.1, PD4.2, P_5.7, R17.2, R18.2, R32.2, TP6.1, TP6.2, TP7.1, TP7.2, U7805.2 (GND), U7812.2 (GND), U7815.2 (GND), U7915.1 (GND); also elsewhere on the board
GR: B_5.4; also elsewhere on the board
GW: C_6.3; also elsewhere on the board
NOISE: N_5.3; also elsewhere on the board
unnamed: A_6.2, B_6.13, C25.1, CR1.2, R33.2
unnamed 204: D_6.12; also elsewhere on the board
unnamed 206: L_5.12; also elsewhere on the board
unnamed 207: B_6.2; also elsewhere on the board
unnamed: B_4.1, C_4.11
unnamed: B_4.6, B_4.13
unnamed: B_5.2, C_6.1
unnamed: B_5.5, C_5.15
unnamed: B_5.6, C_3.6, C_5.9
unnamed: B_5.8, C_4.2
unnamed: B_5.10, C18.1, R31.1
unnamed: B_5.11, R31.2, Y1.2
unnamed: B_5.9, B_5.12, R30.2, Y1.1
unnamed: B_5.13, C18.2, R30.1, R32.1
unnamed 231: B_6.4; also elsewhere on the board
unnamed: B_6.10, C_6.5, D_4.10
unnamed: B_6.11, B_6.12
unnamed 247: D_4.6; also elsewhere on the board
unnamed: C86.1, CR9.2, CR10.2, U7915.2 (VI)
unnamed 281: C_6.11; also elsewhere on the board
unnamed: CR5.2, R55.2
unnamed: C_6.6, D_5.2, D_5.12
unnamed: C_6.8, E_4.1
unnamed: C_6.10, D_6.10
unnamed 317: E_6.6; also elsewhere on the board
unnamed 318: E_6.3; also elsewhere on the board
unnamed 319: E_6.11; also elsewhere on the board
unnamed 321: L_5.13; also elsewhere on the board
unnamed: D_2.8, E_2.8, M_5.11
unnamed: D_2.16, E_2.16, P_5.6
unnamed: D_4.11, D_5.8
unnamed: D_4.12, E_6.8
unnamed: D_5.6, D_5.13
unnamed 346: D_6.1; also elsewhere on the board
unnamed 347: D_6.3, L_5.2; also elsewhere on the board
unnamed: D_6.4, E_5.13
unnamed: D_6.5, D_6.9, E_4.11
unnamed 350: D_6.11; also elsewhere on the board
unnamed: E_5.8, L_6.12
unnamed: E_6.10, R28.2, TP1.1, TP1.2
unnamed 443: M_5.9; also elsewhere on the board
unnamed: L_1.8, L_2.8, L_5.6, M_1.8, M_2.8, N_1.8, N_2.8
unnamed 463: L_5.1; also elsewhere on the board
unnamed: L_5.4, M_5.2
unnamed 465: L_5.10; also elsewhere on the board
unnamed 477: M_5.6; also elsewhere on the board
unnamed 478: M_5.3; also elsewhere on the board
unnamed: N_5.1, N_5.2, P_5.3
unnamed: N_5.6, P_5.5
unnamed 501: N_5.8; also elsewhere on the board
unnamed 525: P_5.1; also elsewhere on the board
unnamed 526: P_5.2; also elsewhere on the board
O2: B_2.3, B_6.9, E_5.10, TP2.1, TP2.2
O_2: B_2.17, C_3.39; also elsewhere on the board
PR27: R27.1; also elsewhere on the board
PR29: C_3.2, C_3.4, C_3.38, C_4.1, C_4.3, C_4.4, C_4.5, C_4.6, C_4.7, C_4.9, C_4.10, C_5.5, C_5.7, D_4.4, D_4.13, R29.1; also elsewhere on the board
R/~WB: B_2.18, C_6.9, D_2.10, D_6.6, E_2.10, E_3.1; also elsewhere on the board
RAMSEL: N_5.4; also elsewhere on the board
RST_: C_3.40, C_5.1, D_4.8, E_6.9; also elsewhere on the board
R_W: B_2.2, C_3.34, TP3.1, TP3.2; also elsewhere on the board
TIMER0: B_5.3, D_4.1, E_5.5, E_6.12; also elsewhere on the board
TIMER1: E_5.1, E_6.2, N_5.10; also elsewhere on the board
TIMER2: E_5.2, E_6.5; also elsewhere on the board
TIMER3: E_5.4, E_6.1, E_6.4, E_6.13, N_5.9; also elsewhere on the board
VGCK: B_2.5; also elsewhere on the board
~ALPHANUM: E_5.6; also elsewhere on the board
~AUDIO: L_6.7; also elsewhere on the board
~BLANK: D_6.13; also elsewhere on the board
~DMACNT: L_6.5; also elsewhere on the board
~DMAGO: L_6.1; also elsewhere on the board
~DMALD: D_4.2; also elsewhere on the board
~DMAPUSH: B_5.1; also elsewhere on the board
~EXPLODE: L_6.4; also elsewhere on the board
~GOSTROBE: B_6.1; also elsewhere on the board
~NOISERESET: L_6.9; also elsewhere on the board
~O2: B_6.8, M_5.10, M_5.12; also elsewhere on the board
~OPTS: E_4.6; also elsewhere on the board
~OUT: L_6.2; also elsewhere on the board
~PMEM: E_4.9, L_3.1
~PROM0: F_1.20, F_2.10, H_1.10, L_1.10, L_2.10, L_3.5
~PROM1: DE_1.20, H_2.10, J_1.10, L_3.6, M_1.10, M_2.10
~PROM2: C_1.20, J_2.10, K_1.10, L_3.7, N_1.10, N_2.10
~SINP0: E_4.4; also elsewhere on the board
~SINP1: E_4.5; also elsewhere on the board
~TEST: C_5.10; also elsewhere on the board
~THUMP: L_6.6; also elsewhere on the board
~VGCK*: C_6.12; also elsewhere on the board
~VMEM: E_4.10; also elsewhere on the board
~VRAM: L_3.12, M_5.1, M_5.4; also elsewhere on the board
~VROM1: L_3.11; also elsewhere on the board
~VROM2: L_3.10; also elsewhere on the board
~VW: M_5.8; also elsewhere on the board
~WDCLR: C_6.4, L_6.3
~ZPAGE: E_4.12, M_5.13

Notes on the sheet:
ROM/PROM CIRCUITRY
RAM CIRCUITRY
POWER INPUT
CLOCK CIRCUIT
POWER RESET AND WATCHDOG TIMER
NMI COUNTER
MPU CIRCUITRY
ADDRESS DECODING CIRCUITRY

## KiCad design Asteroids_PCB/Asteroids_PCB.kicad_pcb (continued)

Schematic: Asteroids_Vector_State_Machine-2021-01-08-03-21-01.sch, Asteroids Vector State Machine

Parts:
A_7: LS74; DIP14
A_8: LS10; DIP14
A_9: LS109; DIP16
A_10: LS157; DIP16
BC_10: LS157; DIP16
B_5: LS04; DIP14
B_6: LS14; DIP14
B_7: LS161; DIP16
B_8: LS08; DIP14
B_9: LS32; DIP14
B_10: LS374; DIP20
C_6: LS00; DIP14
C_7: LS161; DIP16
C_8: S287N; DIP16
C_9: LS191_; DIP16
C_10: LS157; DIP16
DE_10: LS157; DIP16
D_4: LS74; DIP14
D_6: LS02; DIP14
D_7: LS161; DIP16
D_8: LS174_; DIP16
D_9: LS191_; DIP16
D_10: LS374; DIP20
E_5: LS20; DIP14
E_6: LS08; DIP14
E_7, E_8: LS42; DIP16
E_9: LS191_; DIP16
E_10: LS157; DIP16
FH_10: LS157; DIP16
F_3: LS157; DIP16
F_4: LS670; DIP16
F_5: LS193; DIP16
F_6: LS157_; DIP16
F_7: LS273; DIP20
F_8: SN5497; DIP16
F_9: LS191_; DIP16
F_10: LS174_; DIP16
H_3: LS157; DIP16
H_4: LS670; DIP16
H_5: LS193; DIP16
H_6: LS367; DIP16
H_7: LS273; DIP20
H_8: SN5497; DIP16
H_9: LS191_; DIP16
H_10: LS04; DIP14
J_3: LS157; DIP16
J_4: LS670; DIP16
J_5: LS193; DIP16
J_6: LS367; DIP16
J_7: LS273; DIP20
J_8: SN5497; DIP16
J_9: LS191_; DIP16
K_3: LS157; DIP16
K_4: 835185; DIP18
K_5: LS191; DIP16
K_6: LS08; DIP14
K_7: LS273; DIP20
K_8: SN5497; DIP16
L_3: LS139; DIP16
L_4: 835185; DIP18
L_5: LS04; DIP14
M_4: 2114; DIP18
M_5: LS32; DIP14
M_6: LS83; DIP16
M_7: LS175; DIP16
NP_3: 8316E; DDIP24
N_4: 2114; DIP18
N_5: LS00; DIP14
N_6: LS32; DIP14
PD10, PD11, PD30, PD31: Split_Pad; SP
P_4: 2114; DIP18
R1, R2, R3, R4, R5, R6, R7, R8: 22K; GenericR
R130, R131: 10K; GenericR
RP1, RP2: R_Network07_10K; SIP8
R_2: LS245; DIP20
R_4: 2114; DIP18
TP30: DISP; TEST_POINT

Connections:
3MHz: C_6.2, C_6.13, D_4.3, E_5.12; also elsewhere on the board
6MHz: A_7.3, A_9.4, B_10.11, D_10.11, F_10.9; also elsewhere on the board
12KHz: D_6.2; also elsewhere on the board
+5V: A_7.14, A_8.14, A_9.16, A_10.16, BC_10.16, B_5.14, B_6.14, B_7.16, B_8.14, B_9.14, B_10.20, C_6.14, C_7.16, C_8.16, C_9.16, C_10.16, DE_10.16, D_4.14, D_6.14, D_7.16, D_8.16, D_9.16, D_10.20, E_5.14, E_6.14, E_7.16, E_8.16, E_9.16, E_10.16, FH_10.16, F_3.16, F_4.16, F_5.16, F_6.16, F_7.20, F_8.16, F_9.16, F_10.16, H_3.16, H_4.16, H_5.16, H_6.16, H_7.20, H_8.16, H_9.16, H_10.14, J_3.16, J_4.16, J_5.16, J_6.16, J_7.20, J_8.16, J_9.16, K_3.16, K_4.18, K_5.16, K_6.14, K_7.20, K_8.16, L_3.16, L_4.18, L_5.14, M_4.18, M_5.14, M_6.5, M_7.16, NP_3.21, NP_3.24, N_4.18, N_5.14, N_6.14, P_4.18, R1.1, R2.1, R3.1, R4.1, R5.2, R6.2, R7.2, R8.2, R130.2, R131.2, RP1.1, RP2.1, R_2.20, R_4.18; also elsewhere on the board
AB0: F_3.11; also elsewhere on the board
AB1: F_3.5; also elsewhere on the board
AB2: F_3.2; also elsewhere on the board
AB3: F_3.14; also elsewhere on the board
AB4: H_3.14; also elsewhere on the board
AB5: H_3.2; also elsewhere on the board
AB6: H_3.5; also elsewhere on the board
AB7: H_3.11; also elsewhere on the board
AB8: J_3.11; also elsewhere on the board
AB9: J_3.14, N_5.5; also elsewhere on the board
AB10: J_3.2, L_5.5; also elsewhere on the board
AB11: K_3.2, L_3.2; also elsewhere on the board
AB12: D_6.8, E_5.9, K_3.14, L_3.3; also elsewhere on the board
ADMA0: C_8.5, D_8.12, E_8.15, F_3.10
ADMA1: F_3.6, F_4.15, F_5.3
ADMA2: F_3.3, F_4.1, F_5.2
ADMA3: F_3.13, F_4.2, F_5.6
ADMA4: F_4.3, F_5.7, H_3.13
ADMA5: H_3.3, H_4.15, H_5.3
ADMA6: H_3.6, H_4.1, H_5.2
ADMA7: H_3.10, H_4.2, H_5.6
ADMA8: H_4.3, H_5.7, J_3.10
ADMA9: J_3.13, J_4.15, J_5.3
ADMA10: J_3.3, J_4.1, J_5.2
ADMA11: J_4.2, J_5.6, K_3.3
ADMA12: J_4.3, J_5.7, K_3.13
AM0: F_3.9, K_4.5, L_4.5, M_4.5, NP_3.8, N_4.5, P_4.5, R_4.5; also elsewhere on the board
AM1: F_3.7, K_4.6, L_4.6, M_4.6, NP_3.7, N_4.6, P_4.6, R_4.6; also elsewhere on the board
AM2: F_3.4, K_4.7, L_4.7, M_4.7, NP_3.6, N_4.7, P_4.7, R_4.7; also elsewhere on the board
AM3: F_3.12, K_4.4, L_4.4, M_4.4, NP_3.5, N_4.4, P_4.4, R_4.4; also elsewhere on the board
AM4: H_3.12, K_4.3, L_4.3, M_4.3, NP_3.4, N_4.3, P_4.3, R_4.3; also elsewhere on the board
AM5: H_3.4, K_4.2, L_4.2, M_4.2, NP_3.3, N_4.2, P_4.2, R_4.2; also elsewhere on the board
AM6: H_3.7, K_4.1, L_4.1, M_4.1, NP_3.2, N_4.1, P_4.1, R_4.1; also elsewhere on the board
AM7: H_3.9, K_4.17, L_4.17, M_4.17, NP_3.1, N_4.17, P_4.17, R_4.17; also elsewhere on the board
AM8: J_3.9, K_4.16, L_4.16, M_4.16, NP_3.23, N_4.16, P_4.16, R_4.16; also elsewhere on the board
AM9: J_3.12, K_4.15, L_4.15, M_4.15, NP_3.22, N_4.15, P_4.15, R_4.15; also elsewhere on the board
AM10: J_3.4, K_4.8, L_4.8, L_5.3, M_5.5, NP_3.19; also elsewhere on the board
AM11: K_3.4, L_3.14
AM12: K_3.12, L_3.13
BVLD: B_8.8; also elsewhere on the board
DACX1: C_10.9, D_10.13
DACX1*: D_10.12; also elsewhere on the board
DACX2: C_10.7, D_10.14
DACX2*: D_10.15; also elsewhere on the board
DACX3: C_10.12, D_10.17
DACX3*: D_10.16; also elsewhere on the board
DACX4: C_10.4, D_10.18
DACX4*: D_10.19; also elsewhere on the board
DACX5: DE_10.9, D_10.8
DACX5*: D_10.9; also elsewhere on the board
DACX6: DE_10.7, D_10.7
DACX6*: D_10.6; also elsewhere on the board
DACX7: DE_10.12, D_10.4
DACX7*: D_10.5; also elsewhere on the board
DACX8: DE_10.4, D_10.3
DACX8*: D_10.2; also elsewhere on the board
DACX9: E_10.12, F_10.13
DACX9*: F_10.12; also elsewhere on the board
DACX10: E_10.4, F_10.14
DACX10*: F_10.15; also elsewhere on the board
DACY1: A_10.9, B_10.13
DACY1*: B_10.12; also elsewhere on the board
DACY2: A_10.7, B_10.14
DACY2*: B_10.15; also elsewhere on the board
DACY3: A_10.12, B_10.17
DACY3*: B_10.16; also elsewhere on the board
DACY4: A_10.4, B_10.18
DACY4*: B_10.19; also elsewhere on the board
DACY5: BC_10.9, B_10.8
DACY5*: B_10.9; also elsewhere on the board
DACY6: BC_10.7, B_10.7
DACY6*: B_10.6; also elsewhere on the board
DACY7: BC_10.12, B_10.4
DACY7*: B_10.5; also elsewhere on the board
DACY8: BC_10.4, B_10.3
DACY8*: B_10.2; also elsewhere on the board
DACY9: FH_10.9, F_10.6
DACY9*: F_10.7; also elsewhere on the board
DACY10: FH_10.12, F_10.4
DACY10*: F_10.5; also elsewhere on the board
DB0: R_2.16; also elsewhere on the board
DB1: R_2.17; also elsewhere on the board
DB2: R_2.18; also elsewhere on the board
DB3: R_2.15; also elsewhere on the board
DB4: R_2.14; also elsewhere on the board
DB5: R_2.13; also elsewhere on the board
DB6: R_2.12; also elsewhere on the board
DB7: R_2.11; also elsewhere on the board
DDMA0: F_7.18, H_7.18, J_7.18, K_7.18, L_4.14, M_4.14, NP_3.9, N_4.14, R8.1, R_2.4; also elsewhere on the board
DDMA1: F_7.3, H_7.3, J_7.3, K_7.3, L_4.13, M_4.13, NP_3.10, N_4.13, R7.1, R_2.3; also elsewhere on the board
DDMA2: F_7.17, H_7.17, J_7.17, K_7.17, L_4.12, M_4.12, NP_3.11, N_4.12, R6.1, R_2.2; also elsewhere on the board
DDMA3: F_7.4, H_7.4, J_7.4, K_7.4, L_4.11, M_4.11, NP_3.13, N_4.11, R5.1, R_2.5; also elsewhere on the board
DDMA4: F_7.14, H_7.14, J_7.14, K_4.14, K_7.14, NP_3.14, P_4.14, R1.2, R_2.6, R_4.14; also elsewhere on the board
DDMA5: F_7.7, H_7.7, J_7.7, K_4.13, K_7.7, NP_3.15, P_4.13, R2.2, R_2.7, R_4.13; also elsewhere on the board
DDMA6: F_7.13, H_7.13, J_7.13, K_4.12, K_7.13, NP_3.16, P_4.12, R3.2, R_2.8, R_4.12; also elsewhere on the board
DDMA7: F_7.8, H_7.8, J_7.8, K_4.11, K_7.8, NP_3.17, P_4.11, R4.2, R_2.9, R_4.11; also elsewhere on the board
DVX0: E_9.15, J_7.19, J_8.14
DVX1: E_9.1, J_7.2, J_8.15
DVX2: E_9.10, J_7.16, J_8.2
DVX3: E_9.9, J_7.5, J_8.3
DVX4: D_9.15, J_7.15, K_8.4
DVX5: D_9.1, J_7.6, K_8.1
DVX6: D_9.10, J_7.12, K_8.14
DVX7: D_9.9, J_7.9, K_8.15
DVX8: C_9.15, K_7.19, K_8.2
DVX9: C_9.1, K_7.2, K_8.3
DVX10: C_9.5, C_9.10, D_9.5, E_9.5, K_7.16
DVX11: B_6.3, C_9.9, F_6.11, K_7.5
DVY0: H_6.2, H_7.19, H_8.14, J_9.15
DVY1: H_6.14, H_7.2, H_8.15, J_9.1
DVY2: H_6.12, H_7.16, H_8.2, J_9.10
DVY3: H_6.4, H_7.5, H_8.3, J_9.9
DVY4: F_8.4, H_6.10, H_7.15, H_9.15
DVY5: F_8.1, H_6.6, H_7.6, H_9.1
DVY6: F_8.14, H_7.12, H_9.10, J_6.4
DVY7: F_8.15, H_7.9, H_9.9, J_6.2
DVY8: F_7.19, F_8.2, F_9.15, J_6.10
DVY9: F_7.2, F_8.3, F_9.1, J_6.6
DVY10: F_7.16, F_9.5, F_9.10, H_9.5, J_6.12, J_9.5
DVY11: F_6.14, F_7.5, F_9.9, J_6.14
EXPITCH0: L_5.11, N_6.12; also elsewhere on the board
EXPITCH1: N_6.13; also elsewhere on the board
GND: A_7.7, A_8.7, A_9.8, A_10.8, A_10.15, BC_10.8, BC_10.15, B_5.7, B_6.7, B_7.8, B_8.7, B_9.7, B_10.1, B_10.10, C_6.7, C_7.8, C_8.8, C_8.13, C_8.14, C_9.8, C_10.8, C_10.15, DE_10.8, DE_10.15, D_4.7, D_6.7, D_7.8, D_8.8, D_9.8, D_10.1, D_10.10, E_5.7, E_6.7, E_7.8, E_8.8, E_9.8, E_10.6, E_10.8, E_10.15, FH_10.3, FH_10.8, FH_10.15, F_3.8, F_3.15, F_4.8, F_5.8, F_5.14, F_6.5, F_6.8, F_6.15, F_7.10, F_8.8, F_9.8, F_10.8, H_3.8, H_3.15, H_4.8, H_5.8, H_5.14, H_6.8, H_7.10, H_8.1, H_8.4, H_8.8, H_9.8, H_10.7, J_3.8, J_3.15, J_4.8, J_5.8, J_5.14, J_6.8, J_7.10, J_8.1, J_8.4, J_8.8, J_9.8, K_3.8, K_3.15, K_4.9, K_5.1, K_5.4, K_5.8, K_5.9, K_5.10, K_5.15, K_6.7, K_7.10, K_8.8, L_3.8, L_3.15, L_4.9, L_5.7, M_4.9, M_5.7, M_6.12, M_6.13, M_7.8, NP_3.12, NP_3.18, N_4.9, N_5.7, N_6.7, PD30.1, PD30.2, PD31.1, PD31.2, P_4.9, R130.1, R131.1, R_2.10, R_4.9; also elsewhere on the board
GO: A_9.6, B_7.9, C_7.9, D_7.7, D_7.9, D_7.10, H_10.1
GR: B_5.4, F_4.11, H_4.11, J_4.11
GW: C_6.3, F_4.12, H_4.12, J_4.12
HALT: A_9.10, D_8.14; also elsewhere on the board
LOAD1: F_4.10, F_5.15, H_6.3, RP2.3
LOAD2: F_4.9, F_5.1, H_6.13, RP2.4
LOAD3: F_4.7, F_5.10, H_6.11, RP2.6
LOAD4: F_4.6, F_5.9, H_6.5, RP2.5
LOAD5: H_4.10, H_5.15, H_6.9, RP2.7
LOAD6: H_4.9, H_5.1, H_6.7, RP2.8
LOAD7: H_4.7, H_5.10, J_6.5, RP1.3
LOAD8: H_4.6, H_5.9, J_6.3, RP1.2
LOAD9: J_4.10, J_5.15, J_6.9, RP1.5
LOAD10: J_4.9, J_5.1, J_6.7, RP1.6
LOAD11: J_4.7, J_5.10, J_6.11, RP1.7
LOAD12: J_4.6, J_5.9, J_6.13, RP1.8
NOISE: N_5.3; also elsewhere on the board
unnamed 198: B_6.13; also elsewhere on the board
unnamed: A_7.5, A_8.3, A_8.10, A_8.11
unnamed: A_7.8, B_9.5
unnamed: A_7.9, A_8.5
unnamed: A_7.10, A_8.8
unnamed: A_8.1, A_8.2, A_8.13, B_7.15
unnamed: A_8.4, C_8.4, D_6.12, D_8.7
unnamed: A_8.6, E_8.12
unnamed: A_8.9, L_5.12
unnamed: A_9.2, B_6.2
unnamed: A_9.15, B_8.11
unnamed: B_5.2, C_6.1
unnamed 224: B_5.5; also elsewhere on the board
unnamed 225: B_5.6; also elsewhere on the board
unnamed 226: B_5.8; also elsewhere on the board
unnamed 227: B_5.10; also elsewhere on the board
unnamed 228: B_5.11; also elsewhere on the board
unnamed 229: B_5.9, B_5.12; also elsewhere on the board
unnamed 230: B_5.13; also elsewhere on the board
unnamed: B_6.4, F_6.2
unnamed: B_6.10, C_6.5, D_4.10
unnamed: B_6.11, B_6.12
unnamed: B_7.3, E_7.9
unnamed: B_7.4, E_7.10
unnamed: B_7.5, E_7.11
unnamed: B_7.7, B_7.10, C_7.15
unnamed: B_8.3, C_8.15
unnamed: B_8.6, F_5.5
unnamed: B_9.3, K_6.12
unnamed: B_9.6, D_8.9
unnamed: B_9.8, K_6.9
unnamed: B_9.10, D_4.6
unnamed 272: H_10.4; also elsewhere on the board
unnamed 281: C_6.11; also elsewhere on the board
unnamed 305: C_6.6; also elsewhere on the board
unnamed 306: C_6.8; also elsewhere on the board
unnamed: C_6.10, D_6.10
unnamed: C_7.3, E_7.4
unnamed: C_7.4, E_7.5
unnamed: C_7.5, E_7.6
unnamed: C_7.6, E_7.7
unnamed: C_7.7, C_7.10, D_7.15
unnamed: C_8.1, E_6.6
unnamed: C_8.2, E_6.3
unnamed: C_8.3, E_6.11
unnamed: C_8.6, D_8.5, E_8.14
unnamed: C_8.7, D_8.10, E_8.13, L_5.13
unnamed: C_8.9, D_8.6
unnamed: C_8.10, D_8.11
unnamed: C_8.11, D_8.4
unnamed: C_8.12, D_8.13
unnamed: C_9.4, D_9.13
unnamed: C_9.7, H_10.13
unnamed: C_9.14, D_9.14, E_9.14, H_10.6
unnamed 333: M_5.11; also elsewhere on the board
unnamed 337: D_4.11; also elsewhere on the board
unnamed: D_4.12, E_6.8
unnamed 346: D_6.1; also elsewhere on the board
unnamed 347: D_6.3, L_5.2; also elsewhere on the board
unnamed: D_6.4, E_5.13
unnamed 349: D_6.5, D_6.9; also elsewhere on the board
unnamed: D_6.11, D_8.15
unnamed: D_7.4, E_7.1
unnamed: D_7.5, E_7.2
unnamed: D_7.6, E_7.3
unnamed: D_9.4, E_9.13
unnamed 369: E_5.8; also elsewhere on the board
unnamed 370: E_6.10; also elsewhere on the board
unnamed: E_7.12, M_6.15
unnamed: E_7.13, M_6.2
unnamed: E_7.14, M_6.6
unnamed: E_7.15, M_6.9
unnamed: F_5.12, H_5.5
unnamed: F_6.4, M_6.7
unnamed: F_6.7, M_6.16
unnamed: F_6.9, M_6.4
unnamed: F_6.12, M_6.11
unnamed: F_7.1, K_6.3, K_6.4
unnamed: F_8.5, H_8.12
unnamed: F_8.7, H_8.10, H_8.11
unnamed: F_9.4, H_9.13
unnamed: F_9.7, H_10.11
unnamed: F_9.14, H_9.14, H_10.8, J_9.14
unnamed: H_5.12, J_5.5
unnamed: H_7.1, K_6.6
unnamed: H_9.4, J_9.13
unnamed 408: H_10.3; also elsewhere on the board
unnamed: H_10.5, J_8.6
unnamed: H_8.6, H_10.9
unnamed: J_8.10, J_8.11, K_8.7
unnamed: J_8.12, K_8.5
unnamed: K_3.7, M_5.9
unnamed: K_5.14, K_6.8
unnamed: K_6.11, K_7.11
unnamed 460: L_5.6; also elsewhere on the board
unnamed 463: L_5.1; also elsewhere on the board
unnamed: L_5.4, M_5.2
unnamed 465: L_5.10; also elsewhere on the board
unnamed: M_4.8, M_5.6, R_4.8
unnamed: M_5.3, N_4.8, P_4.8
unnamed: M_6.1, M_7.7
unnamed: M_6.3, M_7.10
unnamed: M_6.8, M_7.2
unnamed: M_6.10, M_7.15
unnamed: M_7.9, N_6.8
unnamed 499: N_5.1, N_5.2; also elsewhere on the board
unnamed 500: N_5.6; also elsewhere on the board
unnamed: N_5.8, N_6.9
unnamed 508: N_6.11; also elsewhere on the board
O2: B_6.9, E_5.10; also elsewhere on the board
PR27: F_5.4, F_8.12, F_10.1, H_5.4, J_5.4, K_5.11, K_7.1, K_8.12, M_7.1; also elsewhere on the board
PR29: A_7.1, A_7.4, A_7.13, A_9.5, B_7.1, B_7.6, C_7.1, D_4.4, D_4.13, D_7.1, D_7.3, K_3.6, K_3.10; also elsewhere on the board
R/~WB: C_6.9, D_6.6, K_3.5, R_2.1; also elsewhere on the board
RAMSEL: N_5.4; also elsewhere on the board
RST_: A_9.11, D_4.8, D_8.1, E_6.9, K_6.2; also elsewhere on the board
SCALE0: K_7.15, M_7.13; also elsewhere on the board
SCALE1: K_7.6, M_7.4; also elsewhere on the board
SCALE2: K_7.12, M_7.12; also elsewhere on the board
SCALE3: K_7.9, M_7.5; also elsewhere on the board
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

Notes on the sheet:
VECTOR GENERATOR PROGRAM COUNTER
STATE MACHINE
VECTOR GENERATOR
MEMORY ADDRESS SELECTOR
VECTOR GENERATOR RAM
VECTOR GENERATOR ROM
VECTOR GENERATOR DATA BUFFER
VECTOR GENERATOR MEMORY DATA LATCHES
VECTOR TIMER
X AND Y POSITION COUNTERS

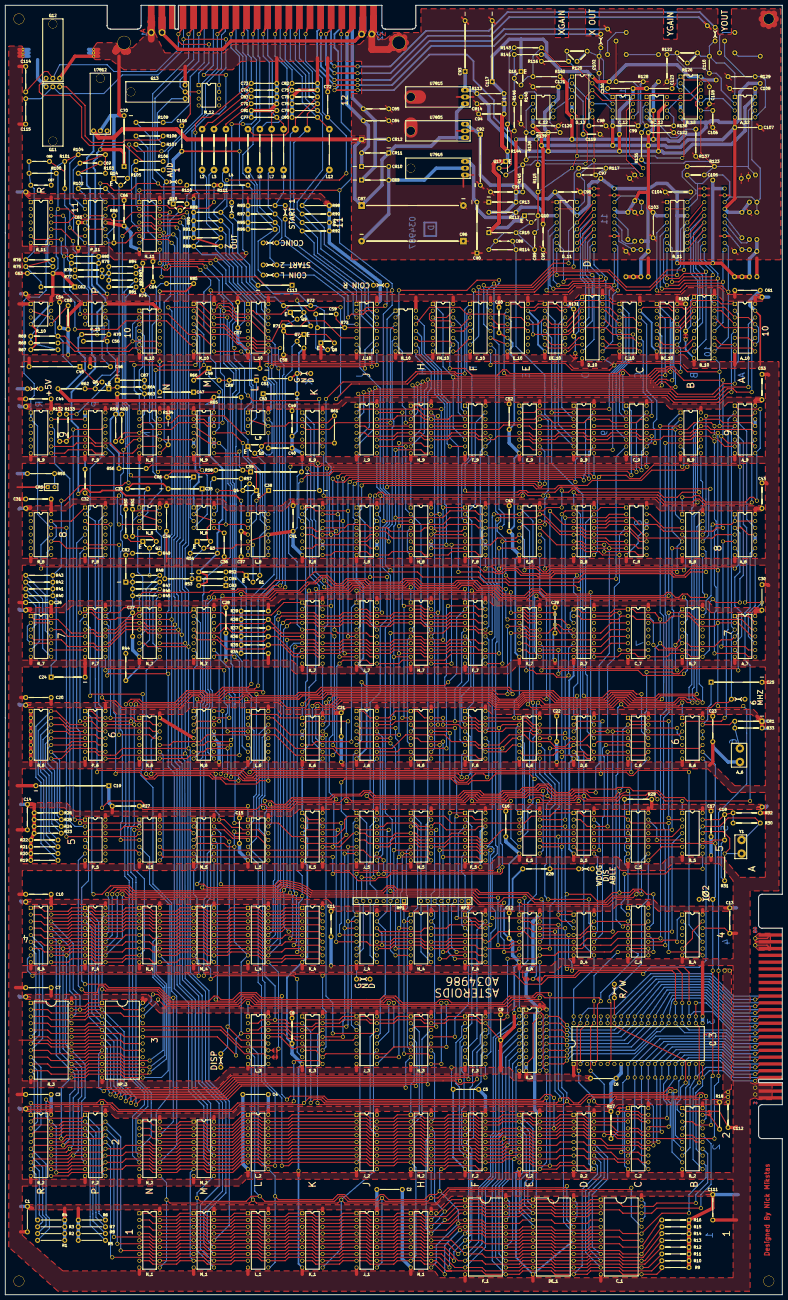
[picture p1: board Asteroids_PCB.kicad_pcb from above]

Board: 2 copper layers, 290.8 x 482.6 mm, 490 parts (1 on the bottom side), 557 nets.

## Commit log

2019-12-17 Transferred prooject into github
    [Asteroids_IO.sch, Asteroids_Microprocessor.sch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]
2021-01-08 Moved the IC silkscreen identifiers to areas they can be seen after soldering
    [Asteroids_IO-2021-01-08-03-21-01.sch, Asteroids_Microprocessor-2021-01-08-03-21-01.sch, Asteroids_PCB-2021-01-08-03-21-01.sch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]
2021-01-08 Changed the silkscreen on the components so the compinent IDs can be seen after soldering
    [Asteroids_PCB-B_Cu.gbl, Asteroids_PCB-B_Mask.gbs, Asteroids_PCB-B_SilkS.gbo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]
2021-01-08 Updated the BOM
2021-01-09 Added the ROM adapter design files and updated the readme file
    [Asteroids_PCB-B_Cu.gbl, Asteroids_PCB-B_Mask.gbs, Asteroids_PCB-B_SilkS.gbo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]
